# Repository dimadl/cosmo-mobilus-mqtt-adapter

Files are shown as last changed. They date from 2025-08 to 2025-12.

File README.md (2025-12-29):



# COSMO Mobilus shutters x Home Assistant (MQTT) Adapter
This repository provides all the necessary information—both software and hardware—to build your own adapter that connects COSMO Mobilus-controlled shutters to Home Assistant via MQTT.

The hardware setup is based on an actual COSMO Mobilus remote control and requires basic soldering skills to complete.

A high-level schematic of the end-to-end solution is shown in the diagram below.

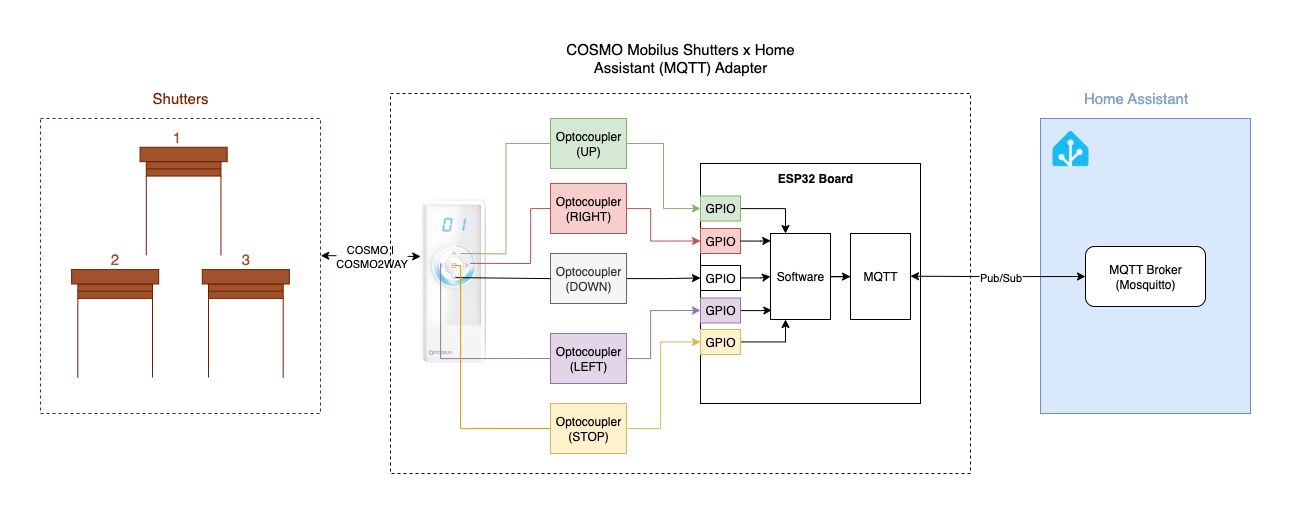
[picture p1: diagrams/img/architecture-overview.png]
Adapter overview


## Motivation
There is no native support for COSMO protocol in Home Assistant.

## Features
- [x] Each shutter is automatically discovered by Home Assistant.
- [x] Position control is supported for each shutter, where 100 represents fully open and 0 fully closed.
- [x] Shutter positions are stored in memory to prevent re-synchronization after restarts.
- [x] The current position of the remote control unit is also saved in memory.

## Schematic
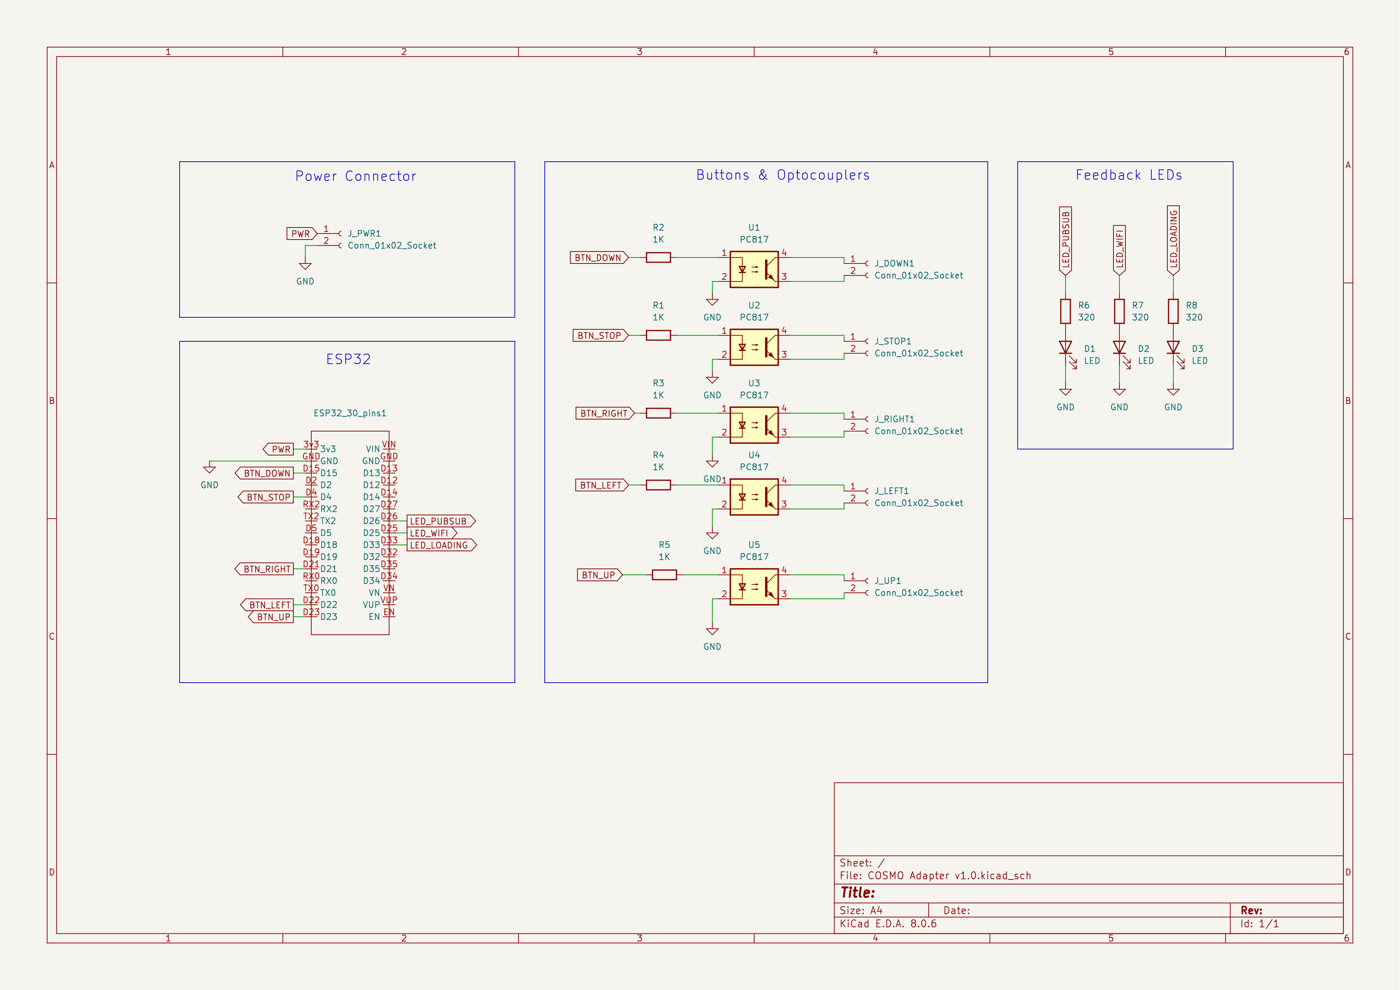
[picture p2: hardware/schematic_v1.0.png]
Schematic


## Supported Device
- Mobilus COSMO HM
- Mobilus COSMO HM1
- Mobilus COSMO HM3+
- Mobilus COSMO G3+ Light (*)
- Mobilus COSMO WM (*)
- Mobilus COSMO L5 (*)
- Mobilus COSMO L1 (*)

(*) - These devices have not been tested; however, given that they use mechanical switches, this approach is expected to work with them as well.

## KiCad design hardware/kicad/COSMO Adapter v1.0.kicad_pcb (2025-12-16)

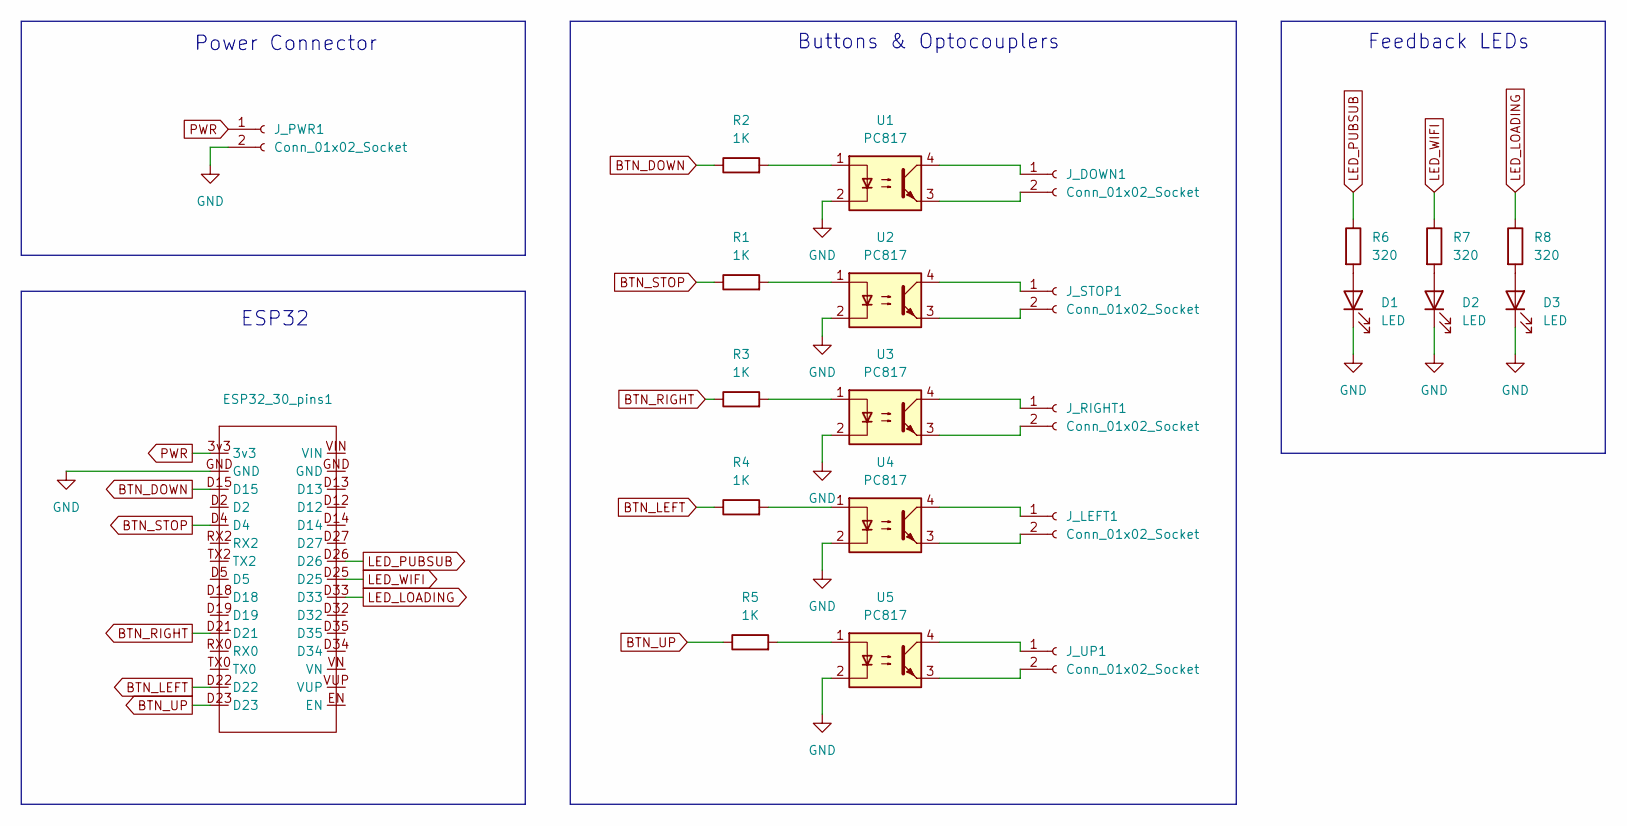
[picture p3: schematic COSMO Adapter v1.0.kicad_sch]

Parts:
D1, D2, D3: LED; LED_D3.0mm
ESP32_30_pins1: ESP_32_DevKit_30
J_DOWN1: Conn_01x02_Socket; PinHeader_1x02_P2.54mm_Vertical
J_LEFT1: Conn_01x02_Socket; PinHeader_1x02_P2.54mm_Vertical
J_PWR1: Conn_01x02_Socket; PinHeader_1x02_P2.54mm_Vertical
J_RIGHT1: Conn_01x02_Socket; PinHeader_1x02_P2.54mm_Vertical
J_STOP1: Conn_01x02_Socket; PinHeader_1x02_P2.54mm_Vertical
J_UP1: Conn_01x02_Socket; PinHeader_1x02_P2.54mm_Vertical
R1, R2, R3, R4, R5: 1K; R_Axial_DIN0207_L6.3mm_D2.5mm_P7.62mm_Horizontal
R6, R7, R8: 320; R_Axial_DIN0207_L6.3mm_D2.5mm_P7.62mm_Horizontal
U1, U2, U3, U4, U5: PC817; DIP-4_W7.62mm

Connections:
BTN_DOWN: ESP32_30_pins1.D15, R2.1
BTN_LEFT: ESP32_30_pins1.D22, R4.1
BTN_RIGHT: ESP32_30_pins1.D21, R3.1
BTN_STOP: ESP32_30_pins1.D4, R1.1
BTN_UP: ESP32_30_pins1.D23, R5.1
GND: D1.1 (K), D2.1 (K), D3.1 (K), ESP32_30_pins1.GND, J_PWR1.2, U1.2, U2.2, U3.2, U4.2, U5.2
LED_LOADING: ESP32_30_pins1.D33, R8.1
LED_PUBSUB: ESP32_30_pins1.D26, R6.1
LED_WIFI: ESP32_30_pins1.D25, R7.1
unnamed: D1.2 (A), R6.2
unnamed: D2.2 (A), R7.2
unnamed: D3.2 (A), R8.2
unnamed: J_DOWN1.1, U1.4
unnamed: J_DOWN1.2, U1.3
unnamed: J_LEFT1.1, U4.4
unnamed: J_LEFT1.2, U4.3
unnamed: J_RIGHT1.1, U3.4
unnamed: J_RIGHT1.2, U3.3
unnamed: J_STOP1.1, U2.4
unnamed: J_STOP1.2, U2.3
unnamed: J_UP1.1, U5.4
unnamed: J_UP1.2, U5.3
unnamed: R1.2, U2.1
unnamed: R2.2, U1.1
unnamed: R3.2, U3.1
unnamed: R4.2, U4.1
unnamed: R5.2, U5.1
PWR: ESP32_30_pins1.3v3, J_PWR1.1

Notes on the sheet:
ESP32
Feedback LEDs
Power Connector
Buttons & Optocouplers

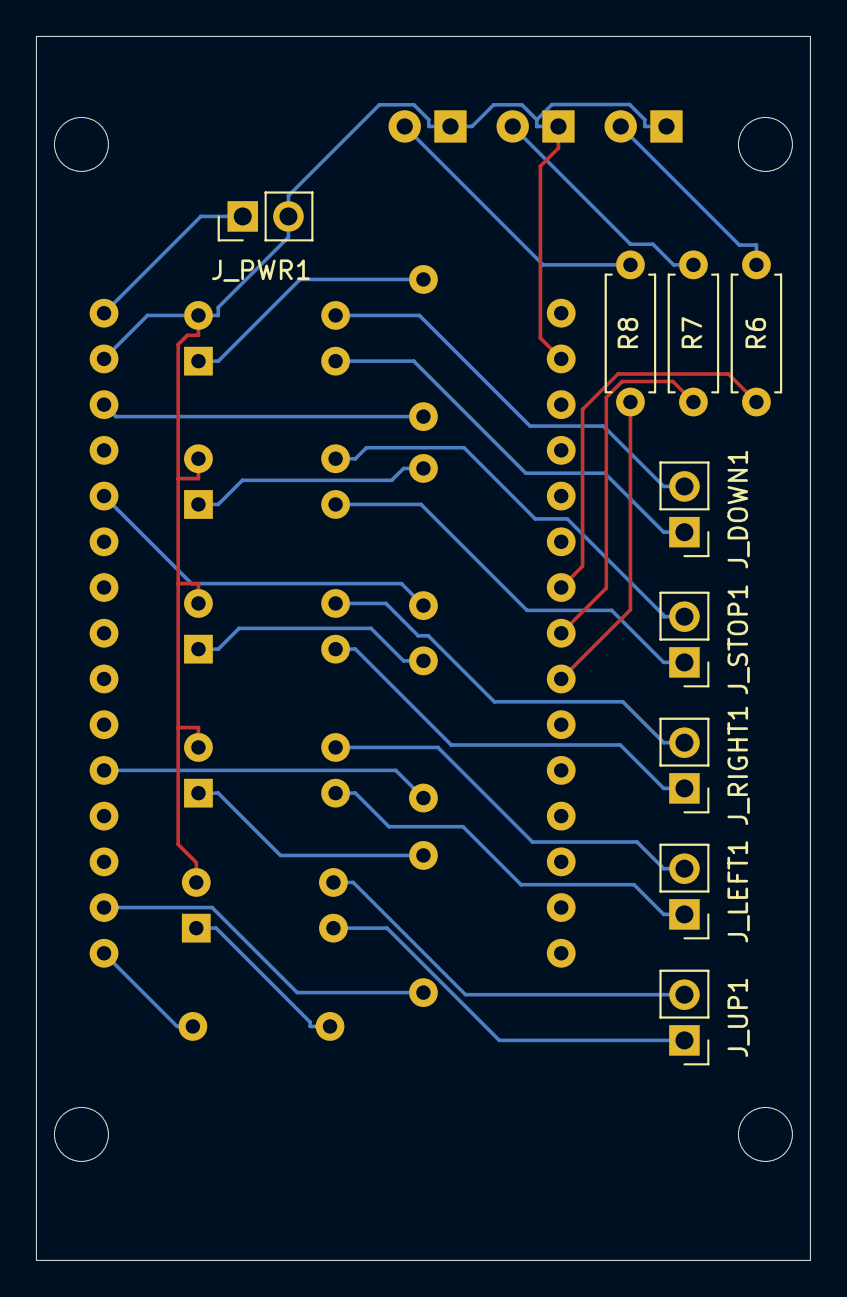
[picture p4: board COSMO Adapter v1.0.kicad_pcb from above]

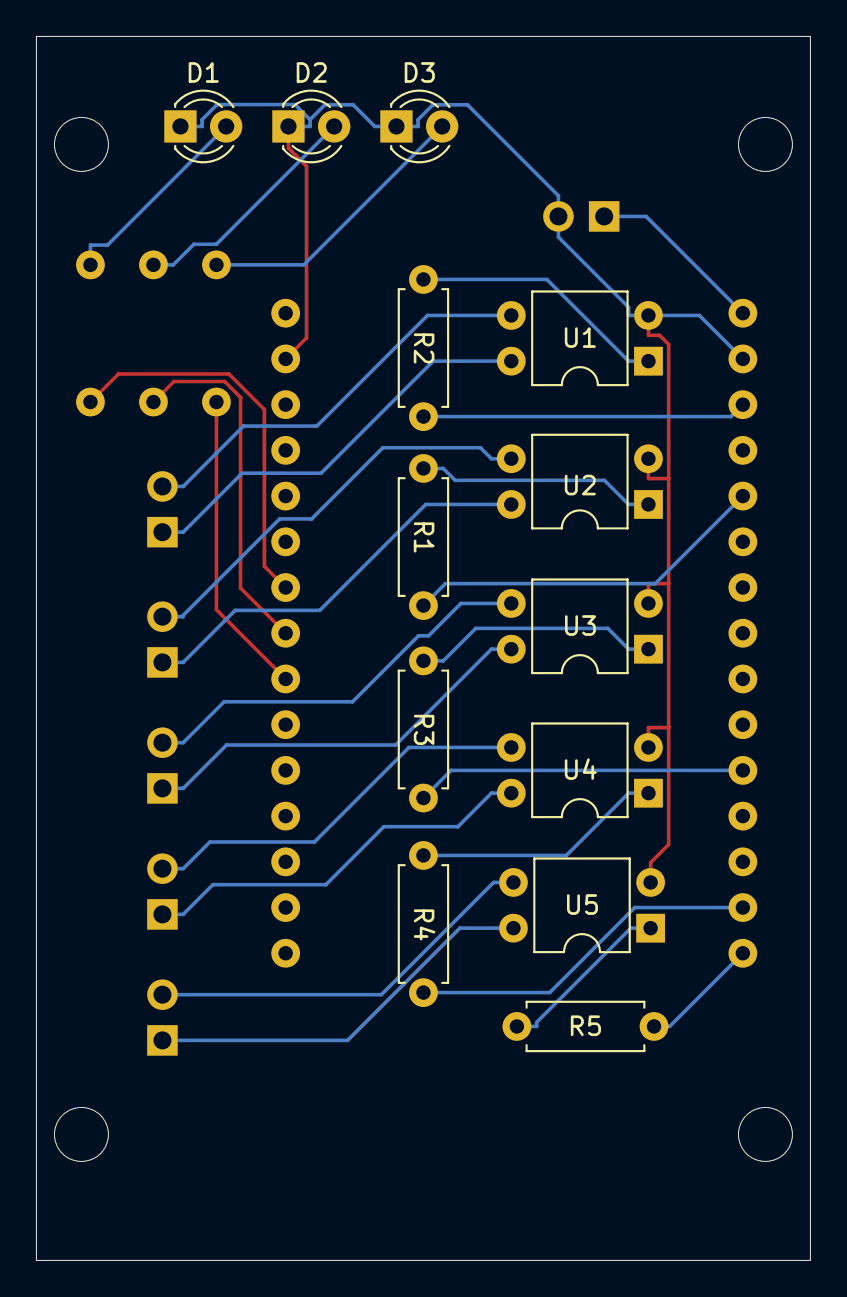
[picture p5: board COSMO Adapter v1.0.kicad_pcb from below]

Board: 2 copper layers, 43.0 x 68.0 mm, 23 parts (13 on the bottom side), 28 nets.

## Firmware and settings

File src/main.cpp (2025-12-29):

#include <Arduino.h>
#include <WiFi.h>
#include <PubSubClient.h>
#include <EEPROM.h>
#include <WiFiManager.h>
#include <Preferences.h>
#include <ArduinoJson.h>

// OTA

#include <AsyncTCP.h>
#include <ESPAsyncWebServer.h>
#include <ElegantOTA.h>

#define HA_MQTT_DEBUG
#include "./ha_mqtt/shutter/HAMQTTShutter.h"
#include "./ha_mqtt/HAMQTTShutterControl.h"
#include "./ha_mqtt/CosmoMobilusHardwareAdapter.h"
#include "./ha_mqtt/mqtt_client/MQTTClient.h"

const char *shuttersConfig = R"rawliteral(
{
  "shutters": [
    {"id": "shutter_kitchen", "name": "Shutter Kitchen", "fullTimeToClose": 16, "index": "7"},
    {"id": "shutter_livingroom", "name": "Shutter Living Room", "fullTimeToClose": 16, "index": "1"},
    {"id": "shutter_livingroom_2", "name": "Shutter Living Room 2", "fullTimeToClose": 16, "index": "2"}, 
    {"id": "shutter_livingroom_3", "name": "Shutter Living Room 3", "fullTimeToClose": 16, "index": "3"}, 
    {"id": "shutter_garden", "name": "Shutter Garden", "fullTimeToClose": 25, "index": "4"}, 
    {"id": "shutter_office", "name": "Shutter Office", "fullTimeToClose": 16, "index": "5"},
    {"id": "shutter_bedroom", "name": "Shutter Bedroom", "fullTimeToClose": 16, "index": "6"}
  ]
}
)rawliteral";

AsyncWebServer server(80);

Preferences preferences;

MQTTClient mqttClient;

ShutterControlPinsAssignment pins = {/* left */ 22, /* right */ 21, /* up */ 23, /* down */ 15, /* stop */ 4};
CosmoMobilusHardwareAdapter hardwareAdapter = CosmoMobilusHardwareAdapter(pins);
HAMQTTShutterControl haMqttControl(mqttClient, hardwareAdapter);

void onOTAStart()
{
  Serial.println("OTA update started!");
}

void onOTAEnd(bool success)
{
  if (success)
  {
    Serial.println("OTA update finished successfully!");
  }
  else
  {
    Serial.println("There was an error during OTA update!");
  }
}

void setup()
{
  // Set software serial baud to 115200;
  Serial.begin(115200);

  EEPROM.begin(10);

  // Load saved parameters from flash
  preferences.begin("config", true);
  String mqtt_broker = preferences.getString("mqtt_broker", "");
  int mqtt_port = preferences.getInt("mqtt_port", 1883);
  String mqtt_username = preferences.getString("mqtt_username", "");
  String mqtt_password = preferences.getString("mqtt_password", "");
  preferences.end();

  // Let Wifi Manager do connection
  WiFiManager wm;

  WiFiManagerParameter custom_mqtt_broker("mqtt_broker", "MQTT Broker", mqtt_broker.c_str(), 40);
  WiFiManagerParameter custom_mqtt_port("mqtt_port", "MQTT Port", String(mqtt_port).c_str(), 6);
  WiFiManagerParameter custom_mqtt_username("mqtt_username", "MQTT Username", mqtt_username.c_str(), 40);
  WiFiManagerParameter custom_mqtt_password("mqtt_password", "MQTT Password", mqtt_password.c_str(), 40, "type='password'");

  wm.addParameter(&custom_mqtt_broker);
  wm.addParameter(&custom_mqtt_port);
  wm.addParameter(&custom_mqtt_username);
  wm.addParameter(&custom_mqtt_password);

  if (mqtt_broker.length() != 0 && mqtt_port != 0 && mqtt_username.length() != 0 && mqtt_password.length() != 0)
  {
    Serial.println("MQTT Paramters exist. Auto connect");
    if (!wm.autoConnect("Cosmo_Mobilus_PD_Adapter", "pd_adapter"))
    {
      Serial.println("Failed to connect and hot timeout. Restarting..");
      ESP.restart();
    }
  }
  else
  {
    Serial.println("MQTT Are not present. Starting the portal...");
    wm.startConfigPortal("Cosmo_Mobilus_PD_Adapter", "pd_adapter");

    if (wm.getWiFiIsSaved())
    {
      // Settings were saved via portal
      Serial.println("WiFi connected.");
      Serial.println("IP address: " + WiFi.localIP().toString());

      mqtt_broker = custom_mqtt_broker.getValue();
      mqtt_port = String(custom_mqtt_port.getValue()).toInt();
      mqtt_username = custom_mqtt_username.getValue();
      mqtt_password = custom_mqtt_password.getValue();

      preferences.begin("config", false);
      preferences.putString("mqtt_broker", mqtt_broker);
      preferences.putInt("mqtt_port", mqtt_port);
      preferences.putString("mqtt_username", mqtt_username);
      preferences.putString("mqtt_password", mqtt_password);
      preferences.end();
    }
  }

  mqttClient.setServer(mqtt_broker.c_str(), mqtt_port, mqtt_username.c_str(), mqtt_password.c_str());

  DynamicJsonDocument shutterConfigResult(1024);
  DeserializationError error = deserializeJson(shutterConfigResult, shuttersConfig);

  if (error)
  {
    Serial.print("JSON parse failed: ");
    Serial.println(error.c_str());
    return;
  }

  JsonArray fields = shutterConfigResult["shutters"];
  for (JsonObject field : fields)
  {
    const char *id = field["id"];
    const char *placeholder = field["name"];

    HAMQTTShutter *shutter = new HAMQTTShutter(field["name"], field["id"], field["fullTimeToClose"], mqttClient);
    haMqttControl.registerShutter(field["index"], shutter);
  }

  haMqttControl.begin();

  // Over The Air updater
  ElegantOTA.begin(&server);
  ElegantOTA.onStart(onOTAStart);
  ElegantOTA.onEnd(onOTAEnd);

  server.begin();
}

void loop()
{
  ElegantOTA.loop();
  mqttClient.loop();
}

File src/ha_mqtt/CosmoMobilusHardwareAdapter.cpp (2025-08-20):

#include "CosmoMobilusHardwareAdapter.h"

CosmoMobilusHardwareAdapter::CosmoMobilusHardwareAdapter(ShutterControlPinsAssignment &pins) : _pins(pins)
{
}

void CosmoMobilusHardwareAdapter::begin()
{
    pinMode(_pins.pinLeft, OUTPUT);
    pinMode(_pins.pinRight, OUTPUT);
    pinMode(_pins.pinUp, OUTPUT);
    pinMode(_pins.pinDown, OUTPUT);
    pinMode(_pins.pinStop, OUTPUT);
}

bool CosmoMobilusHardwareAdapter::pressLeft()
{
    return activatePin(_pins.pinLeft);
}

bool CosmoMobilusHardwareAdapter::pressRight()
{
    return activatePin(_pins.pinRight);
}

bool CosmoMobilusHardwareAdapter::pressUp()
{
    return activatePin(_pins.pinUp);
}

bool CosmoMobilusHardwareAdapter::pressDown()
{
    return activatePin(_pins.pinDown);
}

bool CosmoMobilusHardwareAdapter::pressStop()
{
    return activatePin(_pins.pinStop);
}

bool CosmoMobilusHardwareAdapter::activatePin(uint8_t pin)
{
    // Activate pin represeting the "Left" button
    // Deactivate pin represeting the "Left" button
    // The delay should be very low and adjusted based on the real controller
    digitalWrite(pin, HIGH);
    delay(BUTTON_DELAY);
    digitalWrite(pin, LOW);
    delay(BUTTON_DELAY);

    return true;
}

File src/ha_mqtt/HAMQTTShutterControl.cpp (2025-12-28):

#include <Arduino.h>
#include <PubSubClient.h>
#include "CosmoMobilusHardwareAdapter.h"
#include "HAMQTTHealthCheck.h"
#include "./shutter/HAMQTTShutter.h"
#include "HAMQTTShutterControl.h"

#include <EEPROM.h>

HAMQTTShutterControl *HAMQTTShutterControl::instance = nullptr;

long lastSaved;

void mqttReconnectionCallBack();

HAMQTTShutterControl::HAMQTTShutterControl(MQTTClient &client, CosmoMobilusHardwareAdapter &hardware)
    : _client(client), _hardware(hardware)
{
    instance = this;
}

void HAMQTTShutterControl::setCurrentPosition(uint8_t currentPosition)
{
    // save to memmory to make it available after restart
    EEPROM.write(ADDRESS_POSITION, currentPosition);
    EEPROM.commit();
    Serial.printf("Saving the current position to the memmory %d\n", currentPosition);
    this->currentPosition = currentPosition;
}

uint8_t HAMQTTShutterControl::getCurrentPosition()
{
    // retrieve from memmory
    return this->currentPosition;
}

void HAMQTTShutterControl::initConnection()
{
    this->_client.subscribe(topic_ha_control_command);
    this->_client.subscribe(topic_ha_status);

    // hardware
    _hardware.begin();

    for (uint8_t i = 0; i < 8; i++)
    {
        if (shutters[i])
        {
            shutters[i]->begin();
            shutters[i]->reportPosition(this->latestShutterPositions[i]);
            _client.subscribe(shutters[i]->getCommandTopic());
            _client.subscribe(shutters[i]->getSetPositionTopic());
        }
    }

    healthCHeck->begin();
}

void HAMQTTShutterControl::registerShutter(uint8_t index, HAMQTTShutter *shutter)
{
    // Check if the index is in bound
    this->shutters[index] = shutter;

    // read state from memomory memmory
    uint8_t memShutterPosition = EEPROM.read(index);
    this->latestShutterPositions[index] = memShutterPosition == 255 ? FULLY_OPENED : memShutterPosition;

    Serial.printf("Read the latest position of shutter %d from memmory: %d\n", index, memShutterPosition);
}

void HAMQTTShutterControl::begin()
{
    int8_t memCurrentControlPosition = EEPROM.read(ADDRESS_POSITION);
    this->currentPosition = memCurrentControlPosition == 255 ? 0 : memCurrentControlPosition;
    Serial.printf("Read the current contorl position from memmory: %d\n", memCurrentControlPosition);

    this->_client.setReconnectionCallback(mqttReconnectionCallBack);
    this->_client.setMessageCallback([this](const MqttMessage &msg)
                                     { this->onMqttMessage(msg); });
    this->_client.begin();

    initConnection();
}

void HAMQTTShutterControl::onMqttMessage(const MqttMessage &msg)
{
    String incomingTopic = String(msg.topic);
    String message = String(msg.payload);

    // Healthcheck
    if (strcmp(incomingTopic.c_str(), topic_ha_control_command) == 0 && strcmp(message.c_str(), "ping") == 0)
    {
        Serial.println("Ping received");
        healthCHeck->ping();
        return;
    }

    // Shutter Control
    for (uint8_t shutterIndex = 0; shutterIndex < 8; shutterIndex++)
    {
        if (shutters[shutterIndex] && strcmp(shutters[shutterIndex]->getCommandTopic(), incomingTopic.c_str()) == 0)
        {

            moveToShutterIndex(shutterIndex);

            // adding delay between commands
            delay(500);

            if (message == "CLOSE")
            {
                // WARNING: It's not how it should be implemented.
                // CLOSE command means "start closing" and "close 100%".
                // For now it's mainly for voice controls. Will be re-implemented
                moveToPosition(shutterIndex, FULLY_CLOSED);
            }
            else if (message == "OPEN")
            {
                // WARNING: It's not how it should be implemented.
                // OPEN command means "start openning" and not "open 100%".
                // For now it's mainly for voice controls. Will be re-implemented
                moveToPosition(shutterIndex, FULLY_OPENED);
            }
            else if (message == "STOP")
            {
                // stop();
            }
        }
        else if (shutters[shutterIndex] && strcmp(shutters[shutterIndex]->getSetPositionTopic(), incomingTopic.c_str()) == 0)
        {
            moveToShutterIndex(shutterIndex);

            // adding delay between commands
            delay(500);

            Serial.println("Requested set position");
            // set position of the shutter
            uint8_t requestedPosition = message.toInt();

            // move shutter to the position
            moveToPosition(shutterIndex, requestedPosition);
        }
    }
}

void HAMQTTShutterControl::moveToShutterIndex(uint8_t shutterIndex)
{
    // we know index, but we don't now the current position of the control,
    // so first we should calculate the position and move the control to this position
    Serial.printf("Checking if control movement required to reach %d\n", shutterIndex);
    Serial.printf("Current position is %d\n", getCurrentPosition());

    int8_t diff = shutterIndex - getCurrentPosition();

    Serial.printf("Diff for control %d\n", diff);
    if (diff > 0)
    {
        // then the control should be moved forfward
        moveControlForward(abs(diff));
    }
    else if (diff < 0)
    {
        // then the control should be moved backward
        moveControlBackward(abs(diff));
    }
    else
    {
        // stay on the the same position of the control
    }
    setCurrentPosition(shutterIndex);
}
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

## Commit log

2025-08-03 Adds MQTT support and integration with Home Assistant
    - Enables device discovery in Home Assistant
    - Implements simple callback for the command coming from the HA
    - Starts global refactorings to enable scaling up to several switches
2025-08-09 Prepares the integration to receive commands from MQTT
    - Makes the shutter devices available for setting possition through automatios in Home Assistant
    - Every shutter subscribe to commands from Home Assistant (open, close, stop)
    - Pins initializtion for future optocouplers
2025-08-10 Fixed the issue with topics
    [HAMQTTShutter.cpp, HAMQTTShutterControl.cpp]
2025-08-10 Fixed the issue with positioning the current shutter on the control
    [HAMQTTShutterControl.cpp]
2025-08-20 The first integration with real hardware.
    - Fixed few issues related to button press delays
    - Fixed an issue with moving counter on the hardware forward and backward (added delay to the button)
    [HAMQTTShutterControl.cpp]
2025-08-20 Changed the size of EEPROM and moved current control position initisalization to the begin()
2025-08-21 Implements MQTT Client with fault tolerance and resilience
    - Implements rproxy for PubSubClient
    - Proxies "subscribe()" method with retry policies
    - Proxies "publish()" method with retru policies
    [HAMQTTShutter.cpp, HAMQTTShutterControl.cpp, MQTTClient.cpp]
2025-08-21 Refactors the proxy for MQTTClient
    - Moves MQTT broker initializtion to new proxy client
    - Moves callback inside of HAMQTTShutterControl
    [HAMQTTShutterControl.cpp, MQTTClient.cpp]
2025-08-24 Implements vfeedback on what's happenning inside
    - Adds a strategy that delegates feedback methods to LEDs.
    - Adds a onConnected callback for the MQTTClient. It can be usded to react re-connecrtion. The plan is to re-subscribe when a re-connection happened
2025-09-03 Replaces configuration with user inputs
    - Uses WifiManager to connect to wifi and as manager for MQTT configuration
    - Refactores main.cpp according to the latest changes
    [MQTTClient.cpp, main.cpp]
2025-09-08 Changes pin assignment for Stop button
2025-09-08 Fixes an issue with not saved MQTT config
    [MQTTClient.cpp]
2025-09-13 Adds back-pressure mechanism for messages received from different topic
    - Adds queue between PubSubCclient and a message handler
    - handles messages from queue in a isolated task attached to the second core of processor while the first core processes main sequence
2025-09-13 Adds reboot possibility from HA
    - Listenes for command "reboot" in the dedicated topic. When the message arrives it triggeres reboot mechanism
    [HAMQTTShutterControl.cpp, main.cpp]
2025-12-16 Optimizes the way shutters fully open and fully close
    The code removes unneeded delay between shutters that can be fully closed without pressing the stop button
2025-12-16 Adds Kicad project (schematic, PCB and Gerber files
    [COSMO Adapter v1.0-B_Cu.gbl, COSMO Adapter v1.0-B_Mask.gbs, COSMO Adapter v1.0-B_Paste.gbp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]
2025-12-16 Adds schematic PNG to README.md file
2025-12-28 Adds a health check prosessor based on the ping messages sent from the external system over MQTT.
    - THe entire helath check mechanism relies on the ping messages received from Home Assistant (in my case) over MQTT in the dedicated topic
    - Refactores the previous attempt of the health check and device reboot.
    [HAMQTTShutterControl.cpp]
2026-08-13 Overides the shutters posiotns after device failure
